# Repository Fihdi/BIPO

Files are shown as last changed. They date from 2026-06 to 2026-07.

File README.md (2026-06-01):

# 8hp Dual Bipolar-VCAs / Ring modulators

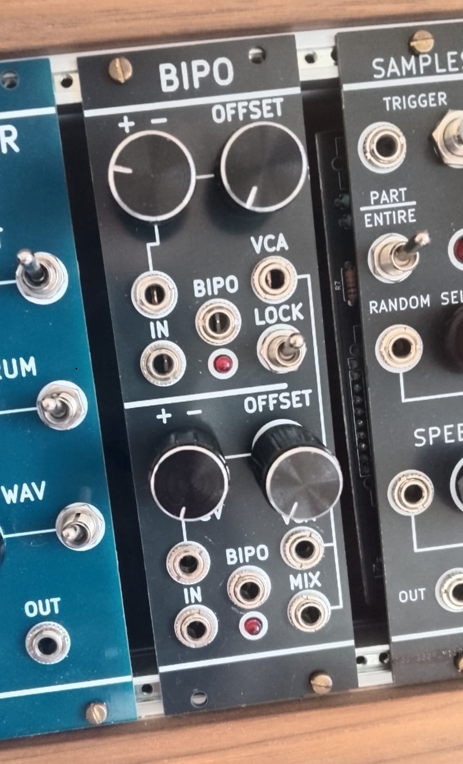
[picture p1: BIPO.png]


BIPO consists of two VCAs which can be used individually or locked together to allow for sidechaining / crossfading. Changing the LEVEL, the VCAs can be biased as to allow each section to be used as a ringmodulator. The resulting ringmodulated signal of the input and the CV is available at the BIPO outputs. The VCA outputs are always summed together at the MIX output.

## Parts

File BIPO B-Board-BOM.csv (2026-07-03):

Reference | Qty | Value | DNP | Exclude from BOM | Exclude from Board | Footprint
C1,C2,C3 | 3 | 100n |  |  |  | Capacitor_SMD:C_1206_3216Metric
D12,D13 | 2 | D_Schottky |  |  |  | Diode_SMD:D_SOD-323_HandSoldering
J10 | 1 | Conn_02x05_Odd_Even |  |  |  | Connector_IDC:IDC-Header_2x05_P2.54mm_Vertical
J103,J105 | 2 | Conn_01x09_Pin |  |  |  | Connector_PinHeader_2.54mm:PinHeader_1x09_P2.54mm_Vertical
Q1,Q2 | 2 | BC857 |  |  |  | Package_TO_SOT_SMD:SOT-23
R1,R2,R13,R25 | 4 | 470R |  |  |  | Resistor_SMD:R_1206_3216Metric
R3,R4,R10,R22 | 4 | 47k |  |  |  | Resistor_SMD:R_1206_3216Metric
R5,R7,R11,R12,R20,R26,R28,R83 | 8 | 10k |  |  |  | Resistor_SMD:R_1206_3216Metric
R6,R8,R9,R14,R15,R16,R17,R18,R19,R21,R23,R24,R27,R29,R30,R31,R32,R34,R35,R38,R39,R41,R42 | 23 | 100k |  |  |  | Resistor_SMD:R_1206_3216Metric
R33,R36,R37,R40,R43 | 5 | 1k |  |  |  | Resistor_SMD:R_1206_3216Metric
RV101,RV102 | 2 | 500k |  |  |  | Potentiometer_THT:Potentiometer_Bourns_3266Y_Vertical
U1,U2 | 2 | TL074 |  |  |  | Package_SO:SOIC-14_3.9x8.7mm_P1.27mm
U3 | 1 | TL072 |  |  |  | Package_SO:SOIC-8_3.9x4.9mm_P1.27mm
U18 | 1 | LM13700 |  |  |  | Package_SO:SOIC-16_3.9x9.9mm_P1.27mm

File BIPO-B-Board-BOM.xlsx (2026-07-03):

 |  |  | BIPO B-Board BOM
Item # | *Designator | *Qty | Manufacturer | *Mfg Part # | Description / Value | *Package/Footprint | Type | Your Instructions / Notes
1 | C1,C2,C3 | 3 |  | C82601 | 100n | Capacitor_SMD:C_1206_3216Metric
2 | D12,D13 | 2 |  | C917117 | 1N4148 | Diode_SMD:D_SOD-323_HandSoldering
3 | J10 | 1 |  |  | Conn_02x05_Odd_Even | Connector_IDC:IDC-Header_2x05_P2.54mm_Vertical |  | DNP
4 | J103,J105 | 2 |  |  | Conn_01x09_Pin | Connector_PinHeader_2.54mm:PinHeader_1x09_P2.54mm_Vertical |  | DNP
5 | Q1,Q2 | 2 |  | C148244 | BC857 | Package_TO_SOT_SMD:SOT-23
6 | R1,R2,R13,R25 | 4 |  | C174050 | 470R | Resistor_SMD:R_1206_3216Metric
7 | R3,R4,R10,R22 | 4 |  | C870758 | 47k | Resistor_SMD:R_1206_3216Metric
8 | R5,R7,R11,R12,R20,R26,R28,R83 | 8 |  | C136889 | 10k | Resistor_SMD:R_1206_3216Metric
9 | R6,R8,R9,R14,R15,R16,R17,R18,R19,R21,R23,R24,R27,R29,R30,R31,R32,R34,R35,R38,R39,R41,R42 | 23 |  | C728669 | 100k | Resistor_SMD:R_1206_3216Metric
10 | R33,R36,R37,R40,R43 | 5 |  | C131398 | 1k | Resistor_SMD:R_1206_3216Metric
11 | RV101,RV102 | 2 |  |  | 500k | Potentiometer_THT:Potentiometer_Bourns_3266Y_Vertical |  | DNP
12 | U1,U2 | 2 |  | C12594 | TL074 | Package_SO:SOIC-14_3.9x8.7mm_P1.27mm
13 | U3 | 1 |  | C67473 | TL072 | Package_SO:SOIC-8_3.9x4.9mm_P1.27mm
14 | U18 | 1 |  | C174050 | LM13700 | Package_SO:SOIC-16_3.9x9.9mm_P1.27mm
Need a quick and accurante quote? Need an efficient production? Please read SMT Ordering Necessary Files & Info in 1 minute. Thank you very much!
Click for Instructions on How to Create a BOM (https://www.pcbway.com/blog/PCB_Assembly/How_to_Build_a_BOM__Bill_Of_Materials_.html)

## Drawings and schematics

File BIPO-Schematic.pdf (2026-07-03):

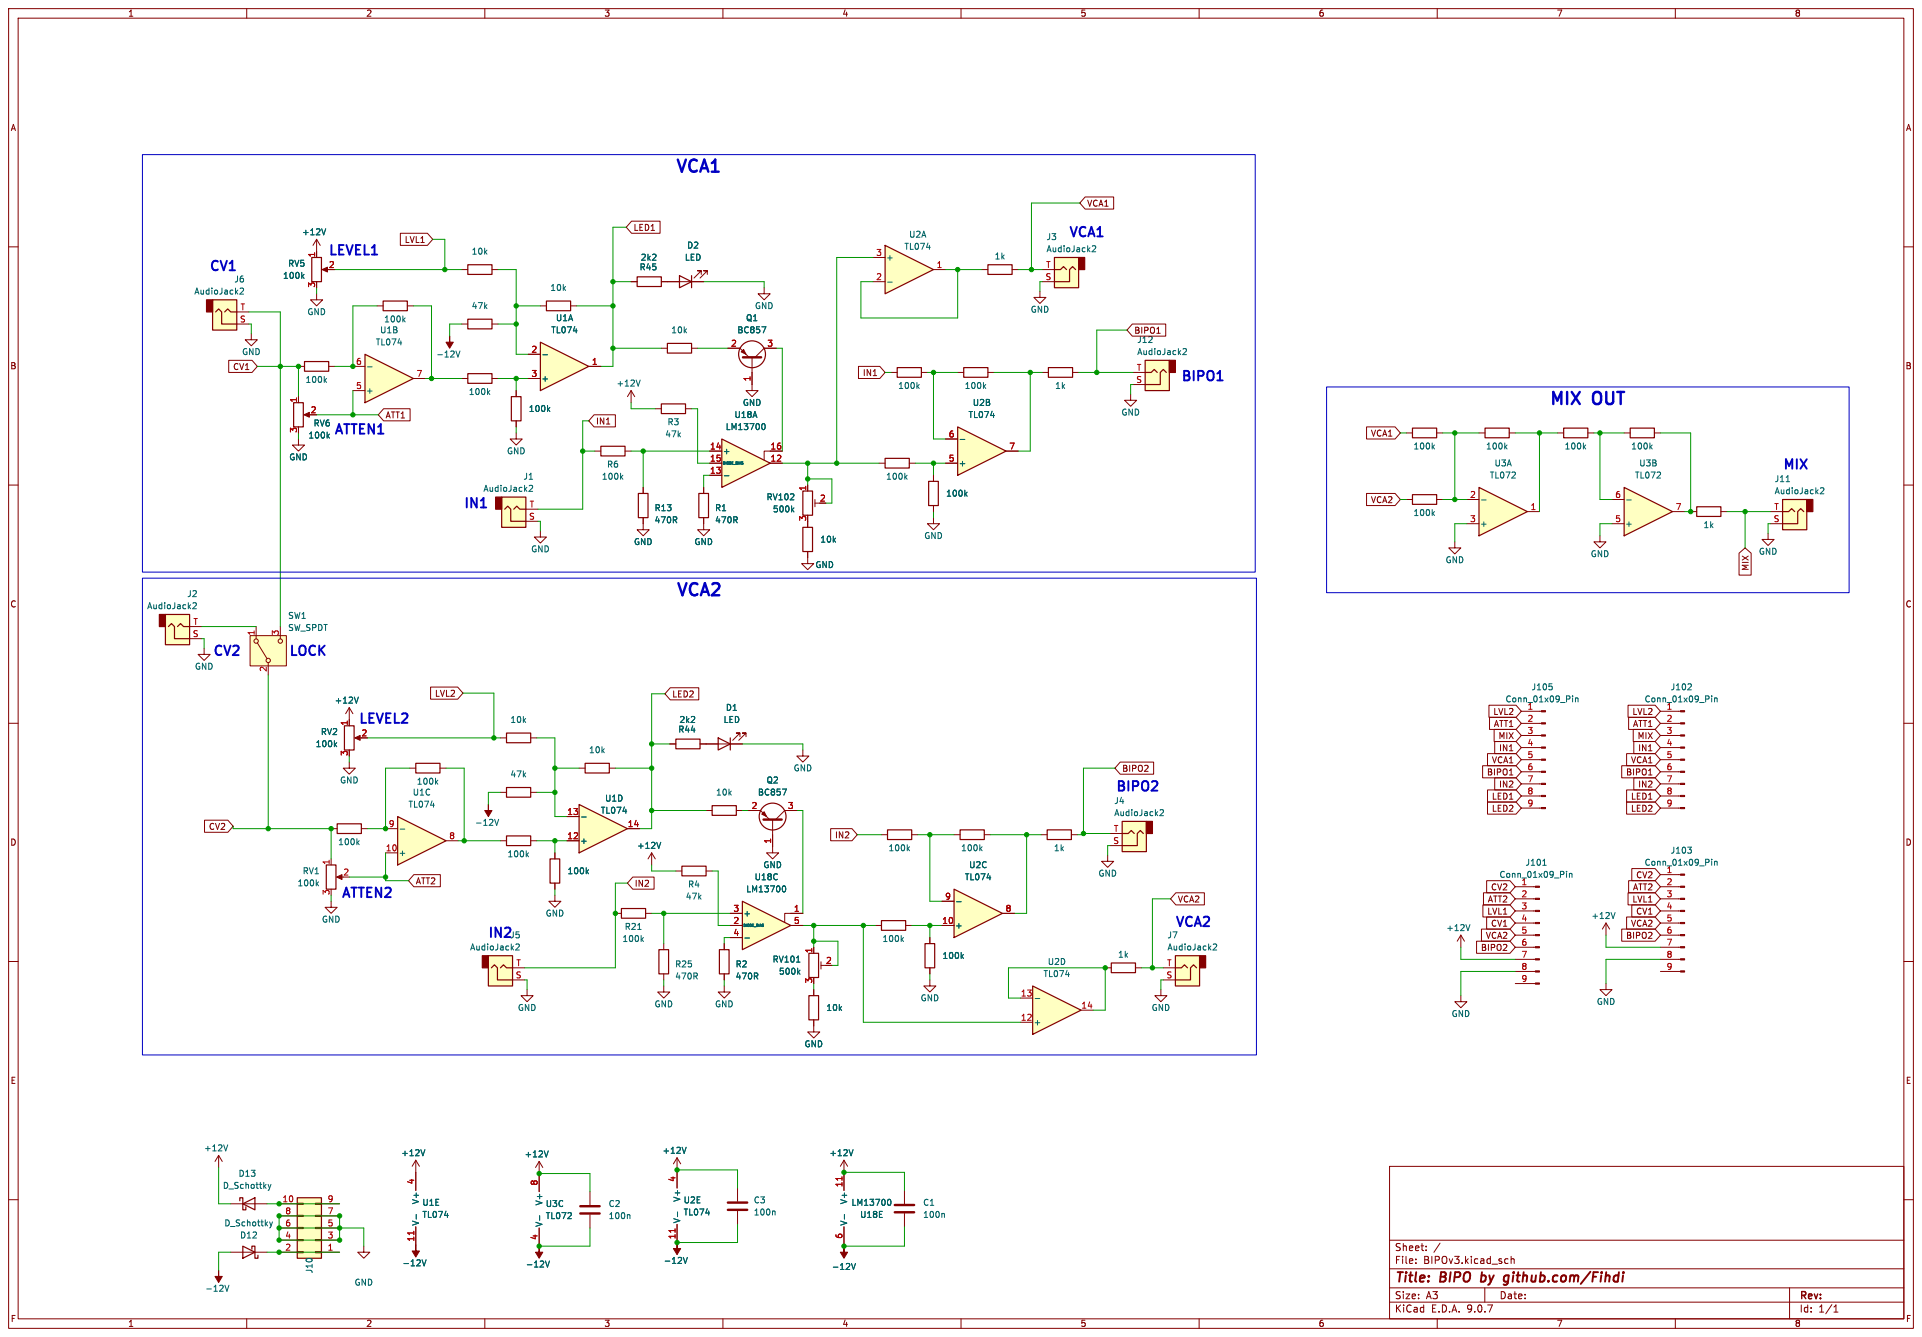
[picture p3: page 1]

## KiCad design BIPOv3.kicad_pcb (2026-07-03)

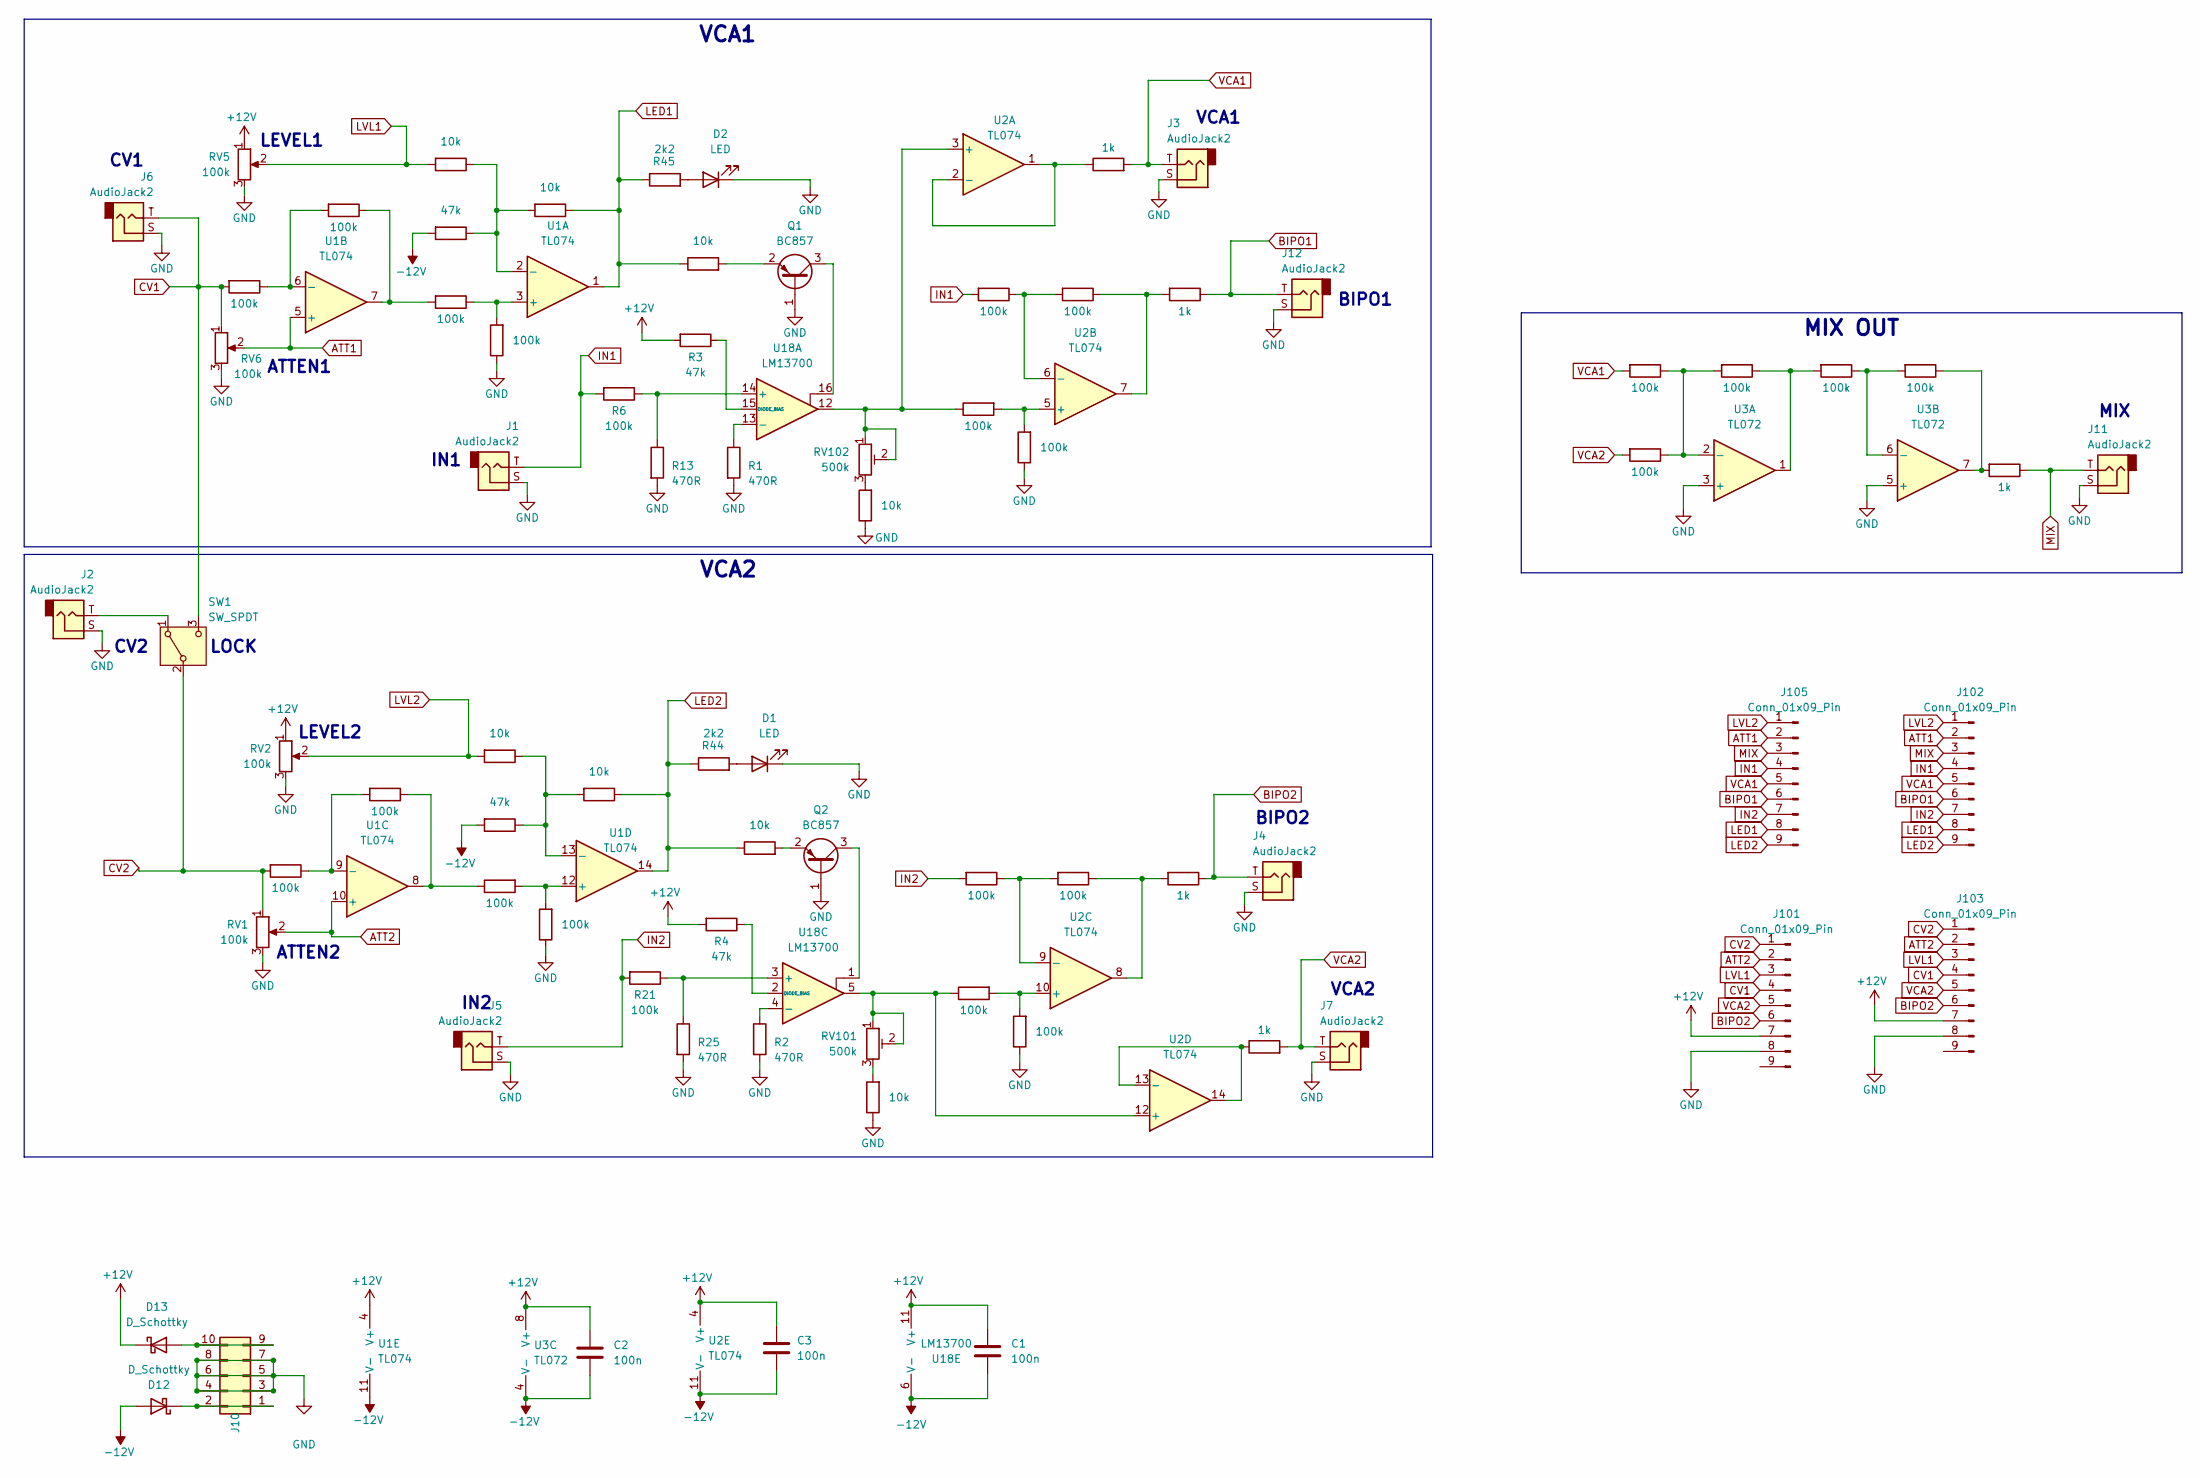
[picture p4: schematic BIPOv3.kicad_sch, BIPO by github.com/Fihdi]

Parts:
C1, C2, C3: 100n; C_1206_3216Metric
D1, D2: LED; LED_D3.0mm
D12, D13: D_Schottky; D_SOD-323_HandSoldering
J1, J2, J3, J4, J5, J6, J7, J11, J12: AudioJack2; MonoTRS
J10: Conn_02x05_Odd_Even; IDC-Header_2x05_P2.54mm_Vertical
J101, J102, J103, J105: Conn_01x09_Pin; PinHeader_1x09_P2.54mm_Vertical
Q1, Q2: BC857; SOT-23
R1, R2, R13, R25: 470R; R_1206_3216Metric
R3, R4, R10, R22: 47k; R_1206_3216Metric
R5, R7, R11, R12, R20, R26, R28, R83: 10k; R_1206_3216Metric
R6, R8, R9, R14, R15, R16, R17, R18, R19, R21, R23, R24, R27, R29, R30, R31, R32, R34, R35, R38, R39, R41, R42: 100k; R_1206_3216Metric
R33, R36, R37, R40, R43: 1k; R_1206_3216Metric
R44, R45: 2k2; R_1206_3216Metric
RV1, RV2, RV5, RV6: 100k; Potentiometer_Alpha_RD901F-40-00D_Single_Vertical
RV101, RV102: 500k; Potentiometer_Bourns_3266Y_Vertical
SW1: SW_SPDT; Switch
U1, U2: TL074; SOIC-14_3.9x8.7mm_P1.27mm
U3: TL072; SOIC-8_3.9x4.9mm_P1.27mm
U18: LM13700; SOIC-16_3.9x9.9mm_P1.27mm

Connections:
+12V: C1.1, C2.1, C3.1, D13.1 (K), J101.7, J103.7, R3.2, R4.2, RV2.1, RV5.1, U1.4 (V+), U2.4 (V+), U3.8 (V+), U18.11 (V+)
-12V: C1.2, C2.2, C3.2, D12.2 (A), R10.2, R22.2, U1.11 (V-), U2.11 (V-), U3.4 (V-), U18.6 (V-)
ATT1: J102.2, J105.2, RV6.2, U1.5 (+)
ATT2: J101.2, J103.2, RV1.2, U1.10 (+)
BIPO1: J12.T, J102.6, J105.6, R36.1
BIPO2: J4.T, J101.6, J103.6, R33.1
CV1: J6.T, J101.4, J103.4, R15.2, RV6.1, SW1.3 (C)
CV2: J101.1, J103.1, R18.2, RV1.1, SW1.2 (B)
GND: D1.1 (K), D2.1 (K), J1.S, J2.S, J3.S, J4.S, J5.S, J6.S, J7.S, J10.3, J10.4, J10.5, J10.6, J10.7, J10.8, J11.S, J12.S, J101.8, J103.8, Q1.1 (B), Q2.1 (B), R1.2, R2.2, R5.1, R7.1, R8.1, R13.2, R24.1, R25.2, R39.1, R42.1, RV1.3, RV2.3, RV5.3, RV6.3, U3.3 (+), U3.5 (+)
IN1: J1.T, J102.4, J105.4, R6.2, R17.2
IN2: J5.T, J102.7, J105.7, R21.2, R34.2
LED1: J102.8, J105.8, R11.1, R45.1, R83.1, U1.1
LED2: J102.9, J105.9, R26.1, R28.1, R44.1, U1.14
LVL1: J101.3, J103.3, R12.2, RV5.2
LVL2: J102.1, J105.1, R20.2, RV2.2
MIX: J11.T, J102.3, J105.3, R37.1
unnamed: D1.2 (A), R44.2
unnamed: D2.2 (A), R45.2
unnamed: D12.1 (K), J10.1, J10.2
unnamed: D13.2 (A), J10.9, J10.10
unnamed: Q1.3 (C), U18.16
unnamed: Q1.2 (E), R83.2
unnamed: Q2.3 (C), U18.1
unnamed: Q2.2 (E), R28.2
unnamed: R5.2, RV102.3
unnamed: R7.2, RV101.3
unnamed: R9.2, R14.1, U1.7
unnamed: R16.1, R36.2, U2.7
unnamed: R19.1, R23.1, U1.8
unnamed: R29.1, R30.2, U3.1
unnamed: R31.1, R37.2, U3.7
unnamed: R33.2, R35.1, U2.8
unnamed: J2.T, SW1.1 (A)
unnamed: R8.2, R9.1, U1.3 (+)
unnamed: R10.1, R11.2, R12.1, U1.2 (-)
unnamed: R14.2, R15.1, U1.6 (-)
unnamed: R18.1, R19.2, U1.9 (-)
unnamed: R23.2, R24.2, U1.12 (+)
unnamed: R20.1, R22.1, R26.2, U1.13 (-)
unnamed: R38.1, RV102.1, RV102.2, U2.3 (+), U18.12
unnamed: R40.1, U2.1, U2.2 (-)
unnamed: R38.2, R39.2, U2.5 (+)
unnamed: R16.2, R17.1, U2.6 (-)
unnamed: R41.2, R42.2, U2.10 (+)
unnamed: R34.1, R35.2, U2.9 (-)
unnamed: R41.1, RV101.1, RV101.2, U2.12 (+), U18.5
unnamed: R43.1, U2.13 (-), U2.14
unnamed: R27.1, R29.2, R32.1, U3.2 (-)
unnamed: R30.1, R31.2, U3.6 (-)
unnamed: R6.1, R13.1, U18.14 (+)
unnamed: R1.1, U18.13 (-)
unnamed: R3.1, U18.15 (DIODE_BIAS)
unnamed: R21.1, R25.1, U18.3 (+)
unnamed: R2.1, U18.4 (-)
unnamed: R4.1, U18.2 (DIODE_BIAS)
VCA1: J3.T, J102.5, J105.5, R27.2, R40.2
VCA2: J7.T, J101.5, J103.5, R32.2, R43.2

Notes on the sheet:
BIPO2
CV1
LEVEL1
VCA1
IN2
LEVEL2
LOCK
IN1
ATTEN1
VCA2
BIPO1
ATTEN2
MIX
CV2
MIX OUT

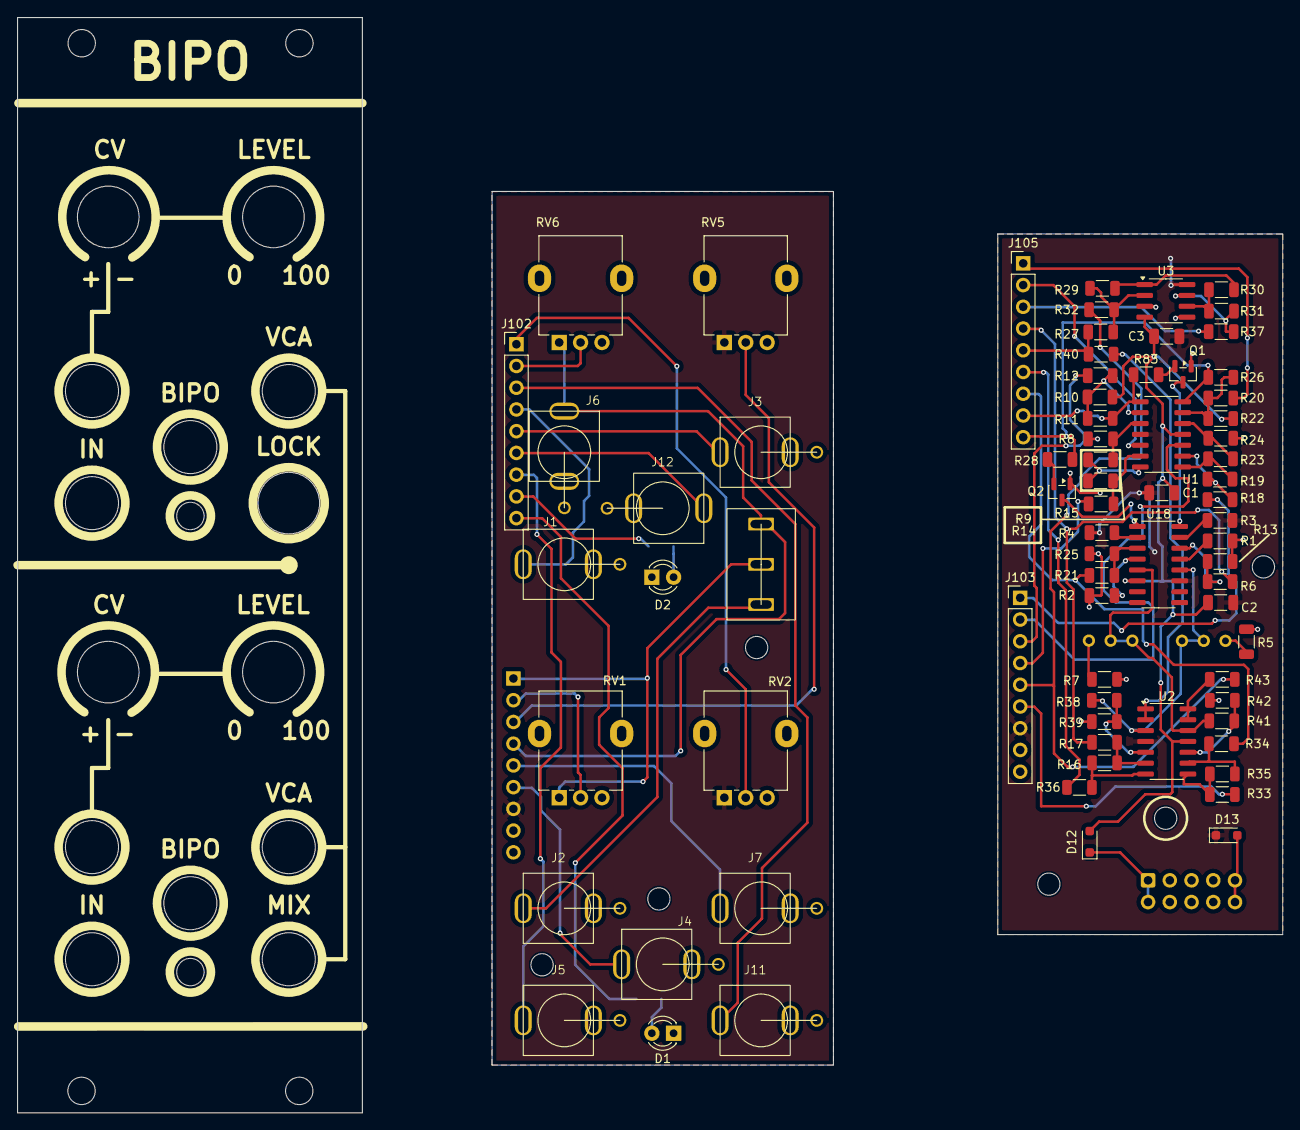
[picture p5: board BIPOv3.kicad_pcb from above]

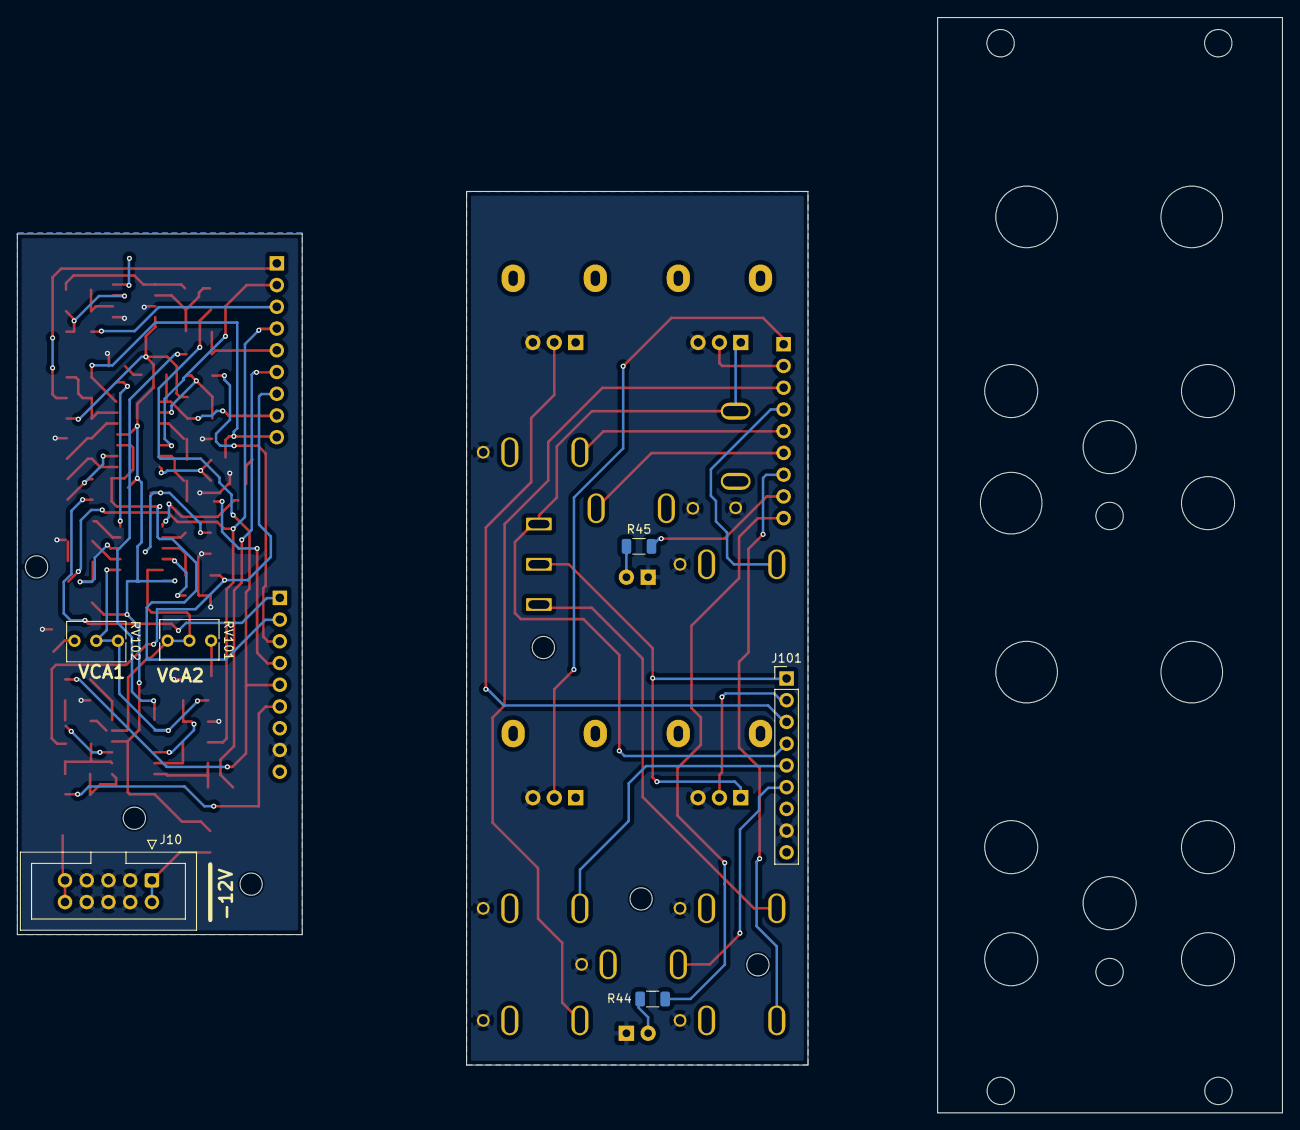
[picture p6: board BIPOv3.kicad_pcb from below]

Board: 2 copper layers, 147.9 x 128.0 mm, 80 parts (6 on the bottom side), 57 nets.
